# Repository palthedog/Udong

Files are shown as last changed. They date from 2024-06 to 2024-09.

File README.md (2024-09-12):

# Udong
Udong is an open-source/open-hardware fighting game controller which supports rapid-trigger.

# How-Tos
## Firmware development
### Requirements
- PlatformIO w/ RP2040 support

TODO: Write more detailed document

## Update WebConf on github.io
`ng build --base-href=/Udong/`

`ng build --configuration=mock --base-href=/Udong/`

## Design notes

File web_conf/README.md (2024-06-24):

# WebConf

## Development server

Run `ng serve` for a dev server. Navigate to `http://localhost:4200/`. The application will automatically reload if you change any of the source files.

## Mocking Udong device

Run `ng serve --configuration=mock` to use a mocked Udong device.
You can develop WebConf app without connecting your Udong device.

## Build

Run `ng build` to build the project. The build artifacts will be stored in the `dist/` directory.

## Running unit tests

Run `ng test` to execute the unit tests via [Karma](https://karma-runner.github.io).

## Running end-to-end tests

Run `ng e2e` to execute the end-to-end tests via a platform of your choice. To use this command, you need to first add a package that implements end-to-end testing capabilities.

## Further help

To get more help on the Angular CLI use `ng help` or go check out the [Angular CLI Overview and Command Reference](https://angular.dev/tools/cli) page.

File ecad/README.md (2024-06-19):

- Setup Kicad

-- Libraries
Install libraries below
-- Keyswitch Kicad Library
can be installed via "Plugin-Content manager" -> Library

-- 3D models
Configure Kicad path so that Kicad can find 3D models saved in our project dir.
In the project's main menu, click "Setting" -> "Configure Paths"
Then, add a new path and
Set Name to `UDONG_DIR` and Path to `(path-to-your-working-directory)/Udong/ecad`

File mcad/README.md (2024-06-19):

- Configure FreeCAD

-- Install Kicad StepUp tool

--- Configure "3D Prefix working dir"
Set "Secondary 3D folder loc" to `(path-to-your-working-directory)/Udong/ecad`

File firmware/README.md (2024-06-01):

# Trouble Shooting

## Failed to install packages (at arduino-pico.git)
```error
VCSBaseException: VCS: Could not process command ['git', 'clone', '--recursive', 'https://github.com/earlephilhower/arduino-pico.git', 'C:\\Users\\safii\\.platformio\\.cache\\tmp\\pkg-installing-l4vwgb1f']
```
You have to enable long-path name on Windows
See: https://arduino-pico.readthedocs.io/en/latest/platformio.html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

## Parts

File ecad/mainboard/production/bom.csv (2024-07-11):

Designator | Footprint | Quantity | Value | LCSC Part #
C1, C2, C20 | 0805 | 3 | 10u
C10, C11, C12, C15, C4, C5, C6, C7, C8, C9 | 0402 | 10 | 100n
C13, C14 | 0402 | 2 | 1uF
C18, C19 | 0402 | 2 | 15p
C21, C22, C23, C24, C25, C26, C27, C28, C29, C30, C31, C32, C33, C34, C35, C36, C37, C38, C39, C40, C41, C42, C43, C44, C45, C46, C47, C48, C49, C50, C51, C52 | 0603 | 32 | 1uF
C3 | 0402 | 1 | 4.7nF
D1 | 0805 | 1 | LED | C2297
J1 | USB_C_Receptacle_HRO_TYPE-C-31-M-12 | 1 | TYPE-C-31-M-12 | C165948
J2 | JST_SH_SM03B-SRSS-TB_1x03-1MP_P1.00mm_Horizontal | 1 | SWD | C160403
K0, K1, K10, K11, K12, K13, K14, K15, K2, K3, K4, K5, K6, K7, K8, K9 | SK20_hall_IC | 16 | DRV5056A3xQDBZxR | C2866615
R1, R30, R9 | 0402 | 3 | 10k
R10, R11 | 0603 | 2 | 27
R13, R32, R5 | 0402 | 3 | 1k
R14, R15, R16, R17, R18, R19, R20, R21, R22, R23, R24, R25, R26, R27, R28, R29 | 0603 | 16 | 100
R2, R3 | 0402 | 2 | 5.1k
R7 | 0402 | 1 | 1M
R8 | 0402 | 1 | 470
SW3, SW4 | MX_Socket | 2 | SW_Push | C5156480
U1 | SOT-223-3_TabPin2 | 1 | NCP1117ST33T3G | C26537
U2 | SOT-23-6 | 1 | USBLC6-2SC6 | C2827654
U22, U23 | SOIC-16_3.9x9.9mm_P1.27mm | 2 | CD4051BM96 | C21379
U3 | SOIC-8_5.23x5.23mm_P1.27mm | 1 | W25Q128JVS
U5 | RP2040-QFN-56 | 1 | RP2040
Y1 | Crystal_SMD_3225-4Pin_3.2x2.5mm | 1 | ABM8-272-T3

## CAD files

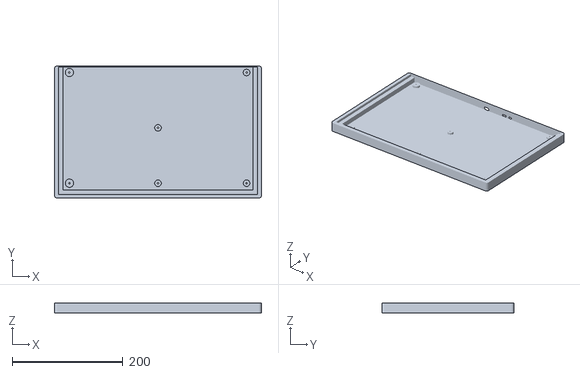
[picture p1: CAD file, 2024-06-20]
mcad/UdongCase-AssemblyBody_3mm.stl
374.0 x 239.0 x 18.0

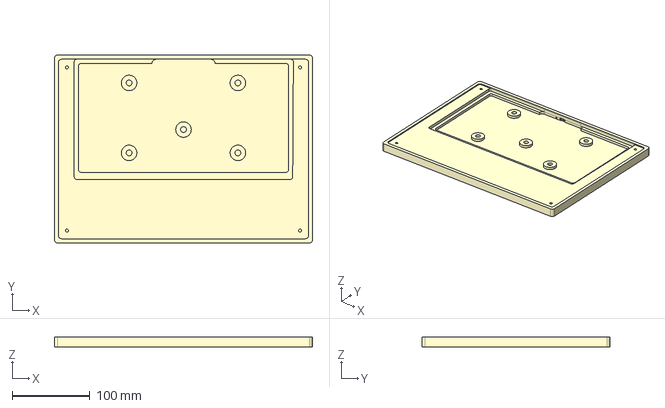
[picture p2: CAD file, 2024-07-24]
mcad/UdongCase.rev2.1.FCStd
332.0 x 242.0 x 13.1 mm

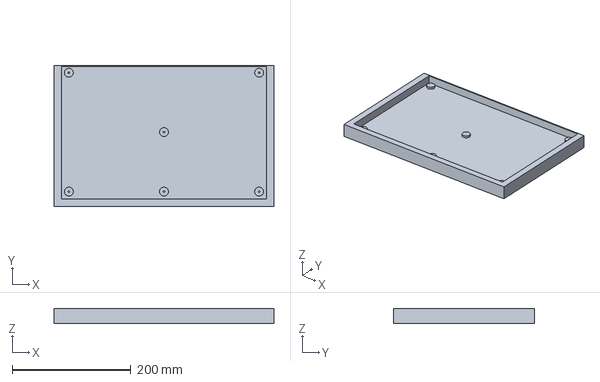
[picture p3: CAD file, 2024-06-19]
mcad/Udong.FCStd
370.0 x 237.0 x 25.0 mm

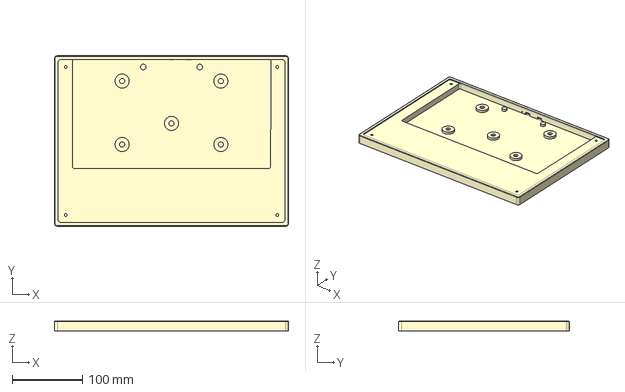
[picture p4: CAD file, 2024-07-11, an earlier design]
mcad/UdongCase.rev2.FCStd
332.0 x 242.0 x 14.7 mm

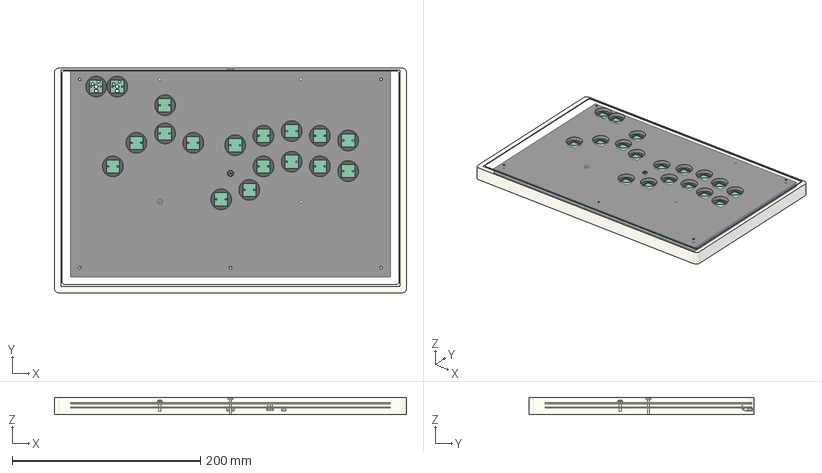
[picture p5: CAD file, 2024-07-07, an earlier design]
mcad/UdongCase.FCStd
374.0 x 239.0 x 18.3 mm
Pcb_1531
ConPins
PcbPins
Mold
Frame
J3_PinSocket_1x03_P254mm_Horizontal_5e44ceccd07"
J2_SM03B-SRSS_0813409b6cc"
Pcb_f4e1
CeilBody
M2.5x16-Screw
M2.5-Washer
M2.5-Washer033
M2.5x10-Screw

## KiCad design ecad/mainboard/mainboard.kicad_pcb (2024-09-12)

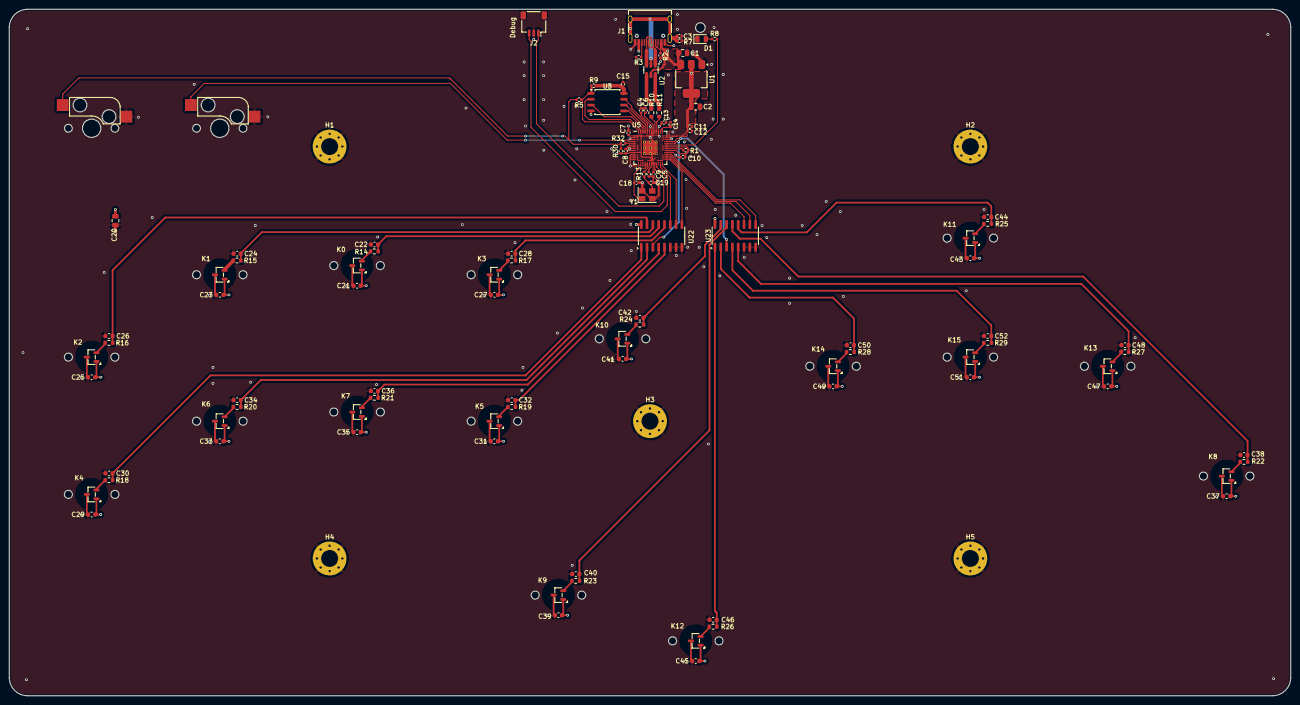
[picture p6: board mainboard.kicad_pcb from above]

Board: 4 copper layers, 280.0 x 150.0 mm, 111 parts (0 on the bottom side), 70 nets.

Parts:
C1, C2, C20: 10u; C_0805_2012Metric
C3: 4.7nF; C_0402_1005Metric
C4, C5, C6, C7, C8, C9, C10, C11, C12, C15: 100n; C_0402_1005Metric
C13, C14: 1uF; C_0402_1005Metric
C18, C19: 15p; C_0402_1005Metric
C21, C22, C23, C24, C25, C26, C27, C28, C29, C30, C31, C32, C33, C34, C35, C36, C37, C38, C39, C40, C41, C42, C43, C44, C45, C46, C47, C48, C49, C50, C51, C52: 1uF; C_0603_1608Metric
D1: LED; LED_0805_2012Metric
H1, H2, H3, H4, H5: MountingHole_Pad; MountingHole_3.7mm_Pad_Via
J1: TYPE-C-31-M-12; USB_C_Receptacle_HRO_TYPE-C-31-M-12
J2: SWD; JST_SH_SM03B-SRSS-TB_1x03-1MP_P1.00mm_Horizontal
K0, K1, K2, K3, K4, K5, K6, K7, K8, K9, K10, K11, K12, K13, K14, K15: DRV5056A3xQDBZxR; SK20_hall_IC
R1, R9, R30: 10k; R_0402_1005Metric
R2, R3: 5.1k; R_0402_1005Metric
R5, R13, R32: 1k; R_0402_1005Metric
R7: 1M; R_0402_1005Metric
R8: 470; R_0402_1005Metric
R10, R11: 27; R_0603_1608Metric
R14, R15, R16, R17, R18, R19, R20, R21, R22, R23, R24, R25, R26, R27, R28, R29: 100; R_0603_1608Metric
SW3, SW4: SW_Push; MX_Socket
U1: NCP1117ST33T3G; SOT-223-3_TabPin2
U2: USBLC6-2SC6; SOT-23-6
U3: W25Q128JVS; SOIC-8_5.23x5.23mm_P1.27mm
U5: RP2040; RP2040-QFN-56
U22, U23: CD4051BM96; SOIC-16_3.9x9.9mm_P1.27mm
Y1: ABM8-272-T3; Crystal_SMD_3225-4Pin_3.2x2.5mm

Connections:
+1V1: C4.1, C5.1, C13.1, U5.23 (DVDD), U5.45 (VREG_VOUT), U5.50 (DVDD)
+3.3V: C2.1, C6.1, C7.1, C8.1, C9.1, C10.1, C11.1, C12.1, C14.1, C15.1, C20.1, C21.2, C23.2, C25.2, C27.2, C29.2, C31.2, C33.2, C35.2, C37.2, C39.2, C41.2, C43.2, C45.2, C47.2, C49.2, C51.2, K0.1 (VCC), K1.1 (VCC), K2.1 (VCC), K3.1 (VCC), K4.1 (VCC), K5.1 (VCC), K6.1 (VCC), K7.1 (VCC), K8.1 (VCC), K9.1 (VCC), K10.1 (VCC), K11.1 (VCC), K12.1 (VCC), K13.1 (VCC), K14.1 (VCC), K15.1 (VCC), R9.1, R30.1, U1.2 (VO), U3.8 (VCC), U5.1 (IOVDD), U5.10 (IOVDD), U5.22 (IOVDD), U5.33 (IOVDD), U5.42 (IOVDD), U5.43 (ADC_AVDD), U5.44 (VREG_IN), U5.48 (USB_VDD), U5.49 (IOVDD), U22.16 (VDD), U23.16 (VDD)
/D+: J1.A6 (D+), J1.B6 (D+), U2.3 (I/O2)
/D-: J1.A7 (D-), J1.B7 (D-), U2.1 (I/O1)
AS0: C22.2, R14.2, U22.13 (X0)
AS1: C24.2, R15.2, U22.14 (X1)
AS2: C26.2, R16.2, U22.15 (X2)
AS3: C28.2, R17.2, U22.12 (X3)
AS4: C30.2, R18.2, U22.1 (X4)
AS5: C32.2, R19.2, U22.5 (X5)
AS6: C34.2, R20.2, U22.2 (X6)
AS7: C36.2, R21.2, U22.4 (X7)
AS8: C38.2, R22.2, U23.13 (X0)
AS9: C40.2, R23.2, U23.14 (X1)
AS10: C42.2, R24.2, U23.15 (X2)
AS11: C44.2, R25.2, U23.12 (X3)
AS12: C46.2, R26.2, U23.1 (X4)
AS13: C48.2, R27.2, U23.5 (X5)
AS14: C50.2, R28.2, U23.2 (X6)
AS15: C52.2, R29.2, U23.4 (X7)
BOOTSEL_SW: R5.2, R30.2, R32.2, SW4.1
DS_0_IN: SW3.1, U5.4 (GPIO2)
DS_1_IN: R32.1, U5.5 (GPIO3)
GND: C1.2, C2.2, C3.2, C4.2, C5.2, C6.2, C7.2, C8.2, C9.2, C10.2, C11.2, C12.2, C13.2, C14.2, C15.2, C18.2, C19.2, C20.2, C21.1, C22.1, C23.1, C24.1, C25.1, C26.1, C27.1, C28.1, C29.1, C30.1, C31.1, C32.1, C33.1, C34.1, C35.1, C36.1, C37.1, C38.1, C39.1, C40.1, C41.1, C42.1, C43.1, C44.1, C45.1, C46.1, C47.1, C48.1, C49.1, C50.1, C51.1, C52.1, D1.1 (K), H1.1, H2.1, H3.1, H4.1, H5.1, J1.A1 (GND), J1.A12 (GND), J1.B1 (GND), J1.B12 (GND), J2.2, K0.3 (GND), K1.3 (GND), K2.3 (GND), K3.3 (GND), K4.3 (GND), K5.3 (GND), K6.3 (GND), K7.3 (GND), K8.3 (GND), K9.3 (GND), K10.3 (GND), K11.3 (GND), K12.3 (GND), K13.3 (GND), K14.3 (GND), K15.3 (GND), R1.2, R2.2, R3.1, R7.2, SW3.2, SW4.2, U1.1 (GND), U3.4 (GND), U5.2 (GPIO0), U5.3 (GPIO1), U5.6 (GPIO4), U5.7 (GPIO5), U5.8 (GPIO6), U5.9 (GPIO7), U5.11 (GPIO8), U5.12 (GPIO9), U5.13 (GPIO10), U5.14 (GPIO11), U5.15 (GPIO12), U5.16 (GPIO13), U5.17 (GPIO14), U5.18 (GPIO15), U5.19 (TESTEN), U5.34 (GPIO22), U5.36 (GPIO24), U5.40 (GPIO28_ADC2), U5.41 (GPIO29_ADC3), U5.57 (GND), U22.6 (INH), U22.7 (VEE), U22.8 (VSS), U23.6 (INH), U23.7 (VEE), U23.8 (VSS), Y1.2, Y1.4
GPIO25: R8.2, U5.37 (GPIO25)
MUX0_A: U5.27 (GPIO16), U22.11 (A)
MUX0_B: U5.28 (GPIO17), U22.10 (B)
MUX0_C: U5.29 (GPIO18), U22.9 (C)
MUX0_OUT: U5.38 (GPIO26_ADC0), U22.3 (X)
MUX1_A: U5.30 (GPIO19), U23.11 (A)
MUX1_B: U5.31 (GPIO20), U23.10 (B)
MUX1_C: U5.32 (GPIO21), U23.9 (C)
MUX1_OUT: U5.39 (GPIO27_ADC1), U23.3 (X)
unnamed: C19.1, R13.2, Y1.3
unnamed: D1.2 (A), R8.1
unnamed: J1.A5 (CC1), R2.1
unnamed: J1.B5 (CC2), R3.2
unnamed: K0.2 (OUT), R14.1
unnamed: K1.2 (OUT), R15.1
unnamed: K2.2 (OUT), R16.1
unnamed: K3.2 (OUT), R17.1
unnamed: K4.2 (OUT), R18.1
unnamed: K5.2 (OUT), R19.1
unnamed: K6.2 (OUT), R20.1
unnamed: K7.2 (OUT), R21.1
unnamed: K8.2 (OUT), R22.1
unnamed: K9.2 (OUT), R23.1
unnamed: K10.2 (OUT), R24.1
unnamed: K11.2 (OUT), R25.1
unnamed: K12.2 (OUT), R26.1
unnamed: K13.2 (OUT), R27.1
unnamed: K14.2 (OUT), R28.1
unnamed: K15.2 (OUT), R29.1
unnamed: R1.1, U5.35 (GPIO23)
unnamed: R11.2, U5.46 (USB_DM)
unnamed: R10.2, U5.47 (USB_DP)
QSPI_SCLK: U3.6 (CLK), U5.52 (QSPI_SCLK)
QSPI_SD0: U3.5 (DI(IO0)), U5.53 (QSPI_SD0)
QSPI_SD1: U3.2 (DO(IO1)), U5.55 (QSPI_SD1)
QSPI_SD2: U3.3 (IO2), U5.54 (QSPI_SD2)
QSPI_SD3: U3.7 (IO3), U5.51 (QSPI_SD3)
QSPI_SS: R5.1, R9.2, U3.1 (~CS), U5.56 (QSPI_SS)
SHIELD: C3.1, J1.S1 (SHIELD), R7.1, U2.2 (GND)
SWCLK: J2.1, U5.24 (SWCLK)
SWD: J2.3, U5.25 (SWD)
USB_D+: R10.1, U2.4 (I/O2)
USB_D-: R11.1, U2.6 (I/O1)
VBUS: C1.1, J1.A4 (VBUS), J1.A9 (VBUS), J1.B4 (VBUS), J1.B9 (VBUS), U1.3 (VI), U2.5 (VBUS)
XIN: C18.1, U5.20 (XIN), Y1.1
XOUT: R13.1, U5.21 (XOUT)

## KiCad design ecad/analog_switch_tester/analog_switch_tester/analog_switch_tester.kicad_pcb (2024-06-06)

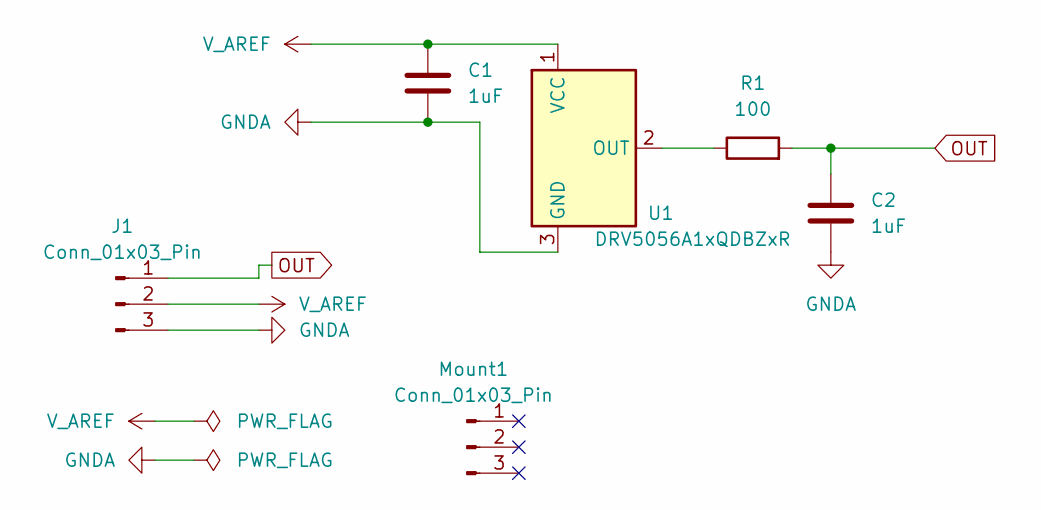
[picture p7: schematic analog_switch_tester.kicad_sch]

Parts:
C1, C2: 1uF; C_0603_1608Metric
J1: Conn_01x03_Pin; PinHeader_1x03_P2.54mm_Vertical
Mount1: Conn_01x03_Pin; PinHeader_1x03_P2.54mm_Vertical
R1: 100; R_0603_1608Metric
U1: DRV5056A1xQDBZxR; SW_Cherry_MX_PCB_1.00u_hall_effect

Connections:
GNDA: C1.1, C2.1, J1.3, U1.3 (GND)
unnamed: R1.1, U1.2 (OUT)
OUT: C2.2, J1.1, R1.2
V_AREF: C1.2, J1.2, U1.1 (VCC)

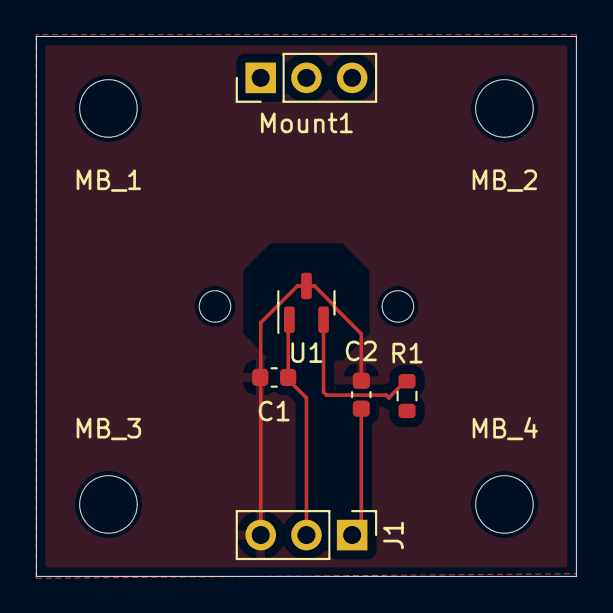
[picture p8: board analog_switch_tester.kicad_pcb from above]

Board: 2 copper layers, 30.0 x 30.0 mm, 10 parts (0 on the bottom side), 4 nets.

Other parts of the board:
MB_1, MB_2, MB_3, MB_4: MountingHole_3.2mm_M3

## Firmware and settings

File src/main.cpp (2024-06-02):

#include <Arduino.h>

#include "Adafruit_TinyUSB.h"
#include "io_utils/led.h"

const uint8_t LED_PIN = D25;

const uint8_t JOY_X_PIN = A0;
const uint8_t JOY_Y_PIN = A1;

// Sample code:
//     https://github.com/adafruit/Adafruit_TinyUSB_Arduino/blob/master/examples/HID/hid_gamepad/hid_gamepad.ino

const uint8_t kHidDescriptor[] = {
    HID_USAGE_PAGE(HID_USAGE_PAGE_DESKTOP),
    HID_USAGE(HID_USAGE_DESKTOP_GAMEPAD),
    HID_COLLECTION(HID_COLLECTION_APPLICATION),

    // 10 bit analog stick (X, Y)
    HID_USAGE_PAGE(HID_USAGE_PAGE_DESKTOP),
    HID_USAGE(HID_USAGE_DESKTOP_X),
    HID_USAGE(HID_USAGE_DESKTOP_Y),
    HID_LOGICAL_MIN_N(-511, 2),
    HID_LOGICAL_MAX_N(512, 2),
    HID_REPORT_COUNT(2),
    HID_REPORT_SIZE(16),
    HID_INPUT(HID_DATA | HID_VARIABLE | HID_ABSOLUTE),

    // 8 bit DPad/Hat Button Map
    HID_USAGE_PAGE(HID_USAGE_PAGE_DESKTOP),
    HID_USAGE(HID_USAGE_DESKTOP_HAT_SWITCH),
    HID_LOGICAL_MIN(1),
    HID_LOGICAL_MAX(8),
    HID_REPORT_COUNT(1),
    HID_REPORT_SIZE(8),
    HID_INPUT(HID_DATA | HID_VARIABLE | HID_ABSOLUTE),

    // 16 buttons
    HID_USAGE_PAGE(HID_USAGE_PAGE_BUTTON),
    HID_USAGE_MIN(1),
    HID_USAGE_MAX(16),
    HID_LOGICAL_MIN(0),
    HID_LOGICAL_MAX(1),
    HID_REPORT_COUNT(16),
    HID_REPORT_SIZE(1),
    HID_INPUT(HID_DATA | HID_VARIABLE | HID_ABSOLUTE),

    // End
    HID_COLLECTION_END,
};

struct TU_ATTR_PACKED GamepadReport {
  int16_t x;    ///< Delta x  movement of left analog-stick
  int16_t y;    ///< Delta y  movement of left analog-stick
  uint8_t hat;  ///< Buttons mask for currently pressed buttons in the DPad/hat
  uint16_t buttons;  ///< Buttons mask for currently pressed buttons
};

Adafruit_USBD_HID usb_hid;

GamepadReport gamepad_report;

Led led(LED_PIN);

void setup() {
  led.StartBlink(1000);

#if defined(ARDUINO_ARCH_MBED) && defined(ARDUINO_ARCH_RP2040)
  // Manual begin() is required on core without built-in support for TinyUSB
  // such as mbed rp2040
  TinyUSB_Device_Init(0);
#endif

  Serial.begin(115200);

  usb_hid.setPollInterval(1);  // 1ms
  usb_hid.setReportDescriptor(kHidDescriptor, sizeof(kHidDescriptor));

  usb_hid.begin();

  // Wait for the USB device to be mounted
  while (!TinyUSBDevice.mounted()) {
    delay(1);
  }
  pinMode(JOY_X_PIN, INPUT);
  pinMode(JOY_Y_PIN, INPUT);

  if (!usb_hid.ready()) {
    Serial.print("ERRROR: Failed to begin Gamepad device");
    return;
  }

  gamepad_report.x = 0;
  gamepad_report.y = 0;
  gamepad_report.hat = GAMEPAD_HAT_CENTERED;
  gamepad_report.buttons = 0;
  usb_hid.sendReport(0, &gamepad_report, sizeof(gamepad_report));
}

void loop() {
  led.Step();

  int joy_x = analogRead(JOY_X_PIN);
  int joy_y = analogRead(JOY_Y_PIN);

  // map [0, 1023] to  [-511, 512]
  gamepad_report.x = joy_x - 511;
  gamepad_report.y = joy_y - 511;

  // temporal D-pad impl.
  gamepad_report.hat = (time_us_32() / 1000000) % 9;

  uint32_t tmp = (time_us_32() / 1000000) % 17;
  if (tmp == 0) {
    gamepad_report.buttons = 0;
  } else {
    gamepad_report.buttons = 1 << (tmp - 1);
  }

  usb_hid.sendReport(0, &gamepad_report, sizeof(gamepad_report));

  Serial.printf("rx: %d, ry: %d\n", gamepad_report.x, gamepad_report.y);

  return;
}

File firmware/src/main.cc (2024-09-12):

#include <Adafruit_TinyUSB.h>
#include <Adafruit_USBD_CDC.h>
#include <Arduino.h>

#include <memory>

#define TELEPLOT 0

#include <hardware/adc.h>

#include "io_utils/io.h"
#include "io_utils/multi_sampling.h"
#include "io_utils/multiplexer.h"
#include "io_utils/soft/hall.h"
#include "serial.h"
#include "throttling.h"
#include "udong.h"

// Sample code:
//     https://github.com/adafruit/Adafruit_TinyUSB_Arduino/blob/master/examples/HID/hid_gamepad/hid_gamepad.ino

const uint32_t kAdcBits = 12;

SerialHandler serial_handler;

void OnReportSent();
Udong udong(OnReportSent);

uint32_t sent_time = 0;
void OnReportSent() {
  serial_handler.PushAnalogSwitchState(udong);

  uint32_t now = time_us_32();
  uint32_t dt_ms = (now - sent_time) / 1000;
  if (dt_ms > 10) {
    Serial.printf(
        "Low polling rate detected: %lu Hz, dt: %lu ms\n", 1000 / dt_ms, dt_ms);
  }

  sent_time = now;
}

void setup() {
  analogReadResolution(kAdcBits);
  adc_init();

#if defined(ARDUINO_ARCH_MBED) && defined(ARDUINO_ARCH_RP2040)
  // Manual begin() is required on core without built-in support for TinyUSB
  // such as mbed rp2040
  TinyUSB_Device_Init(0);
#endif

  TinyUSBDevice.clearConfiguration();

  // https://github.com/obdev/v-usb/blob/master/usbdrv/USB-IDs-for-free.txt
  const uint16_t VID = 0x16c0;
  const uint16_t PID = 0x27dc;
  TinyUSBDevice.setID(VID, PID);
  TinyUSBDevice.setVersion(0x0200);             // USB2.0
  TinyUSBDevice.setLanguageDescriptor(0x0409);  // English/US
  TinyUSBDevice.setProductDescriptor("Udong");
  TinyUSBDevice.setSerialDescriptor("f13g.com:1");

  Serial.begin(921600);  // Well, baud rate doesn't matter for USB CDC.
  Serial.setStringDescriptor("Udong");
  TinyUSBDevice.addInterface(Serial);

  if (!udong.SetupHidDevices()) {
    Serial.println("Failed to setup HID devices");
  }

  // Wait for Serial
  /*
  while (!Serial) {
    sleep_ms(100);
  }
  //*/

  udong.Setup();
}

inline int16_t map_u16_s16(uint16_t v) {
  return (uint32_t)v - (1 << 15);
}

Throttling teleplot_runner(10, []() {
#if TELEPLOT
  for (size_t i = 0; i < 8; i++) {
    udong.GetAnalogSwitches()[i]->TelePrint();
  }
#endif
});

void loop() {
  serial_handler.HandleSerial(udong);

#if TELEPLOT
  teleplot_runner.MaybeRun(time_us_32());
#endif

  udong.Loop();
}

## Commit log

2024-06-02 add led.h
2024-06-02 move led.h into io_utils/
2024-06-04 debug in/out for analog switches
2024-06-05 very initial kicad project for analog switch tester
    [analog_switch_tester.kicad_pcb, analog_switch_tester.kicad_sch]
2024-06-05 Add low-pass filters
    [analog_switch_tester.kicad_sch]
2024-06-06 plot gerber files
    [analog_switch_tester-B_Cu.gbr, analog_switch_tester-B_Mask.gbr, analog_switch_tester-B_Paste.gbr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]
2024-06-07 Measure a pressed depth from a measured magnetic flux. - Calibrate/Solve Br(remenance) from Br_near, Br_far, KeyStroke(4mm) - Create a look-up table from magnetic-flux to pressed depth
2024-06-07 Connect hall-ICs to AnalogSwitch class
2024-06-09 add noise filter
2024-06-09 Calibrate zero point
2024-06-09 save/load calibration data on to the file system.
2024-06-10 set VID/PID
2024-06-14 Intial changes for supporting switch grouping
2024-06-14 add a toggle button to switch rapid/static trigger mode
2024-06-14 switch configurator even when the user select same group
2024-06-14 construct Circuit from UdonConfig
2024-06-15 8 buttons yay!
2024-06-16 place parts except analog switches
    [analog_switches.kicad_sch, digital_switches.kicad_sch, mainboard.kicad_pcb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]
2024-06-16 place all parts
    [mainboard.kicad_pcb]
2024-06-16 replace some parts. Just BEFORE running autoroute
    [mainboard.kicad_pcb]
2024-06-17 fix all DRC errors for connected parts
    [mainboard.kicad_pcb, mainboard.kicad_sch]
2024-06-17 refactor some patterns
    [freerouting.dsn, mainboard.kicad_pcb, mainboard.kicad_sch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]
2024-06-17 Udong board rev.1
    [mainboard.kicad_pcb, mainboard.kicad_sch]
2024-06-17 add new footprints but broken pcb
    [mainboard.kicad_pcb, mainboard.kicad_sch]
2024-06-18 Made a top-plate for Udong Mainboard
    [bom.csv, designators.csv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]
2024-06-19 add 3d model for type-c socket
2024-06-19 WIP: PCB case
    [Udong.FCStd, analog_switches.kicad_sch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]
2024-06-19 bottom case
    [UdongCase.FCStd]
2024-06-20 Very initial housing data.
    [UdongCase-AssemblyBody_3mm.stl, UdongCase.FCStd]
2024-06-20 Put labels about button assignment on User.comments layer
    [mainboard.kicad_pcb]
2024-06-21 prepare for the rev.1 board
    [mainboard.kicad_sch]
2024-06-24 fix: init Serial before use
    [main.cc]
2024-06-24 render buttons with SVG
2024-06-24 Show button name
2024-06-24 WebConf: Support changing button assignments
2024-06-24 Support running the server with mocked Udong device
2024-06-24 Firmware records button assigmnent
2024-06-24 Firmware: button assignment
2024-06-24 ButtonId supports d-pad now
2024-06-26 Sample proto file
2024-06-26 save/load firmware config in protobuf wire format
2024-07-01 delay 1 micro second for waiting the Multiplexer to finish switching the output/input
2024-07-04 switch from nanopb to decaproto
2024-07-05 Support Digital Switch
2024-07-06 Configure platformio to use Debug Probe
    [mainboard.kicad_sch]
2024-07-07 Update circuit for the new design
    [UdongCase.FCStd, mainboard.kicad_pcb, mainboard.kicad_sch]
2024-07-07 Update PCB. Next task would be move switch positions
    [analog_switches.kicad_sch, mainboard.kicad_pcb, mainboard.kicad_sch]
2024-07-07 Now, Webconf is the root source of switchs coordinates
    [mainboard.kicad_pcb]
2024-07-07 New button coordinates
2024-07-08 Make a DigitalSwitch field so that scripts can configure digital-switch related parts easily
    [analog_switches.kicad_sch, mainboard.kicad_pcb]
2024-07-08 Python script to update switch positions
    [analog_switches.kicad_sch, mainboard.kicad_pcb]
2024-07-08 Place all buttons
    [mainboard.kicad_pcb, mainboard.kicad_sch]
2024-07-11 rev2 board
    [UdongCase.rev2.FCStd, analog_switches.kicad_sch, bom.csv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]
2024-07-11 Board config
2024-07-11 Separate board specific code and shared code
2024-07-11 Stop saving calibration data. Instead, just initialize the table with a range data with much margin
2024-07-12 Put readonly board_name.txt on LittleFS filesystem so that our firmware can distinguish board type at runtime without using different firmwares for different boards
2024-07-14 Temporal work around for a dead-lock issue: https://github.com/adafruit/Adafruit_TinyUSB_Arduino/issues/238
    [serial.cc]
2024-07-14 communicate with the board realtime
2024-07-14 Implements an RPC to print an analog switch state on Web Configulator.
2024-07-15 Add Board definition for prototype2
2024-07-15 WebConf: Select the 1st analog button by default
2024-07-15 Firmware: Print a log when detect a low polling rate.
    As far as I checked, it happens only when the firmware encodes proto message.
2024-07-15 WebConf: Show only important info on the graph
    For example, hide the actuation point while the switch is triggered
2024-07-16 WebConf: Clear obsolte data
    Clear obsolte data when:
    - Serial port is disconnected
    - Select a different switch
2024-07-17 WebConf: Mouse wheel for zooming in/out the preview graph
2024-07-24 Adds a new case CAD which has minor fixes from rev2
    1. rev2 had a bad gap between topplate and pcb board.
    2. Closes a hole for the debug port (it's pretty difficult to insert the cable through the hole)
    3. Add rounded edge to support the pcb board so that we can keep the distance between pcb and the switch as close as we can.
    [UdongCase.rev2.1.FCStd]
2024-09-12 Hardware version 1.0
    [designators.csv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]
